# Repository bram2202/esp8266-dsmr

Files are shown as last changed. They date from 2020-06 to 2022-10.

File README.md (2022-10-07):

# PLEASE NOTE, THIS PROJECT IS NO LONGER BEING MAINTAINED
The same functionality can be achieved with [[EspHome]](https://esphome.io/components/sensor/dsmr.html?highlight=dsmr).<br/>
The PCB can be used with the correct [[CONFIG]](https://gist.github.com/bram2202/d75b34a9d672cc8032f55d6f79cfb718)
* * *

# esp8266-dsmr

A ESP8266 based DSMR reader, posting messages onto MQTT.<br/>
Can be powered directly from the meter itself, no external power supply needed*.<br/>
<sup><i>* if enough power can be supplied by the meter.</i></sup>

The code should work on DSRM v2.2 and higher, only tested on V4.2.<br/>
Supports Dutch and Belgian smart meters.<br/>

Can be used with Home Assistant (mqtt auto discover)

## Board in action
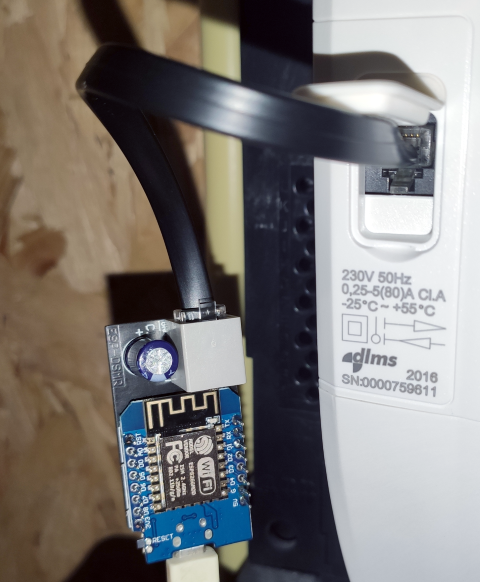
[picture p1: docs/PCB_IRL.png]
esp8266-dsmr


## Requirements 
* Arduino IDE / VS code
* ESP8266 board (Wemos/LOLIN D1 mini/ESP01/NodeMCU)
* Basic soldering and wiring skills
* (For Wemos d1 mini) CH340G driver [[link]](https://wiki.wemos.cc/downloads)
* Prototype board / breadboard / PCB
* RJ11/12/25 cable

## Library dependencies
- [PubSubClient](https://pubsubclient.knolleary.net) - MQTT client
- [Core for ESP8266](https://github.com/esp8266/Arduino) - Arduino core for ESP8266 WiFi chip

## Home Assistant

If MQTT Discovery is enabled in Home Assistant [INFO](https://www.home-assistant.io/docs/mqtt/discovery/), <br/>
the majority of the entities are auto-created and can be found on the integration page.<br/>
Its posible to disale the gas and phase entities in the settings, [See Settings](#Settings).

## Messages

The `MQTT_TOPIC` consists of "ESP_DSMR_" + ESP chip ID.<br/>
For example: `ESP_DSMR_C491F3`

### Info
| Name | unit | DSMR code | MQTT topic |
|:----  |:---|:--- |:---|
| DSMR version | - | 1-3:0.2.8 | <MQTT_TOPIC>/version | 
| Status | online | - | <MQTT_TOPIC>/status | 

### Power
| Name | unit | DSMR code | MQTT topic |
|:----  |:---|:--- |:---|
| current power consumption | kW | 1-0:1.7.0 | <MQTT_TOPIC>/power/consumption | 
| current power production | kW | 1-0:2.7.0 | <MQTT_TOPIC>/power/production | 
| total consumption tariff 1 | kWh | 1-0:1.8.1 | <MQTT_TOPIC>/power/total_consumption_tariff_1 |
| total consumption tariff 2 | kWh | 1-0:1.8.2 | <MQTT_TOPIC>/power/total_consumption_tariff_2 |
| total production tariff 1 | kWh | 1-0:2.8.1 | <MQTT_TOPIC>/power/total_production_tariff_1 |
| total production tariff 2 | kWh | 1-0:2.8.2 | <MQTT_TOPIC>/power/total_production_tariff_2 |
| power tariff | [See tariffs](#tariffs) | 0-0:96.14.0 | <MQTT_TOPIC>/power/power_tariff |
| short power outages | - | 0-0:96.7.21 |<MQTT_TOPIC>/power/short_power_outages |
| long power outages | - | 0-0:96.7.9 |<MQTT_TOPIC>/power/long_power_outages |
| instant current phase 1 | A | 1-0:31.7.0 |<MQTT_TOPIC>/power/phase_1/current |
| instant current phase 2 | A | 1-0:51.7.0 |<MQTT_TOPIC>/power/phase_2/current |
| instant current phase 3 | A | 1-0:71.7.0 |<MQTT_TOPIC>/power/phase_3/current |
| instant consumption phase 1 | kW | 1-0:21.7.0 |<MQTT_TOPIC>/power/phase_1/consumption |
| instant consumption phase 2 | kW | 1-0:41.7.0 |<MQTT_TOPIC>/power/phase_2/consumption |
| instant consumption phase 3 | kW | 1-0:61.7.0 |<MQTT_TOPIC>/power/phase_3/consumption |
| instant production phase 1 | kW | 1-0:22.7.0 |<MQTT_TOPIC>/power/phase_1/production |
| instant production phase 2 | kW | 1-0:42.7.0 |<MQTT_TOPIC>/power/phase_2/production |
| instant production phase 3 | kW | 1-0:62.7.0 |<MQTT_TOPIC>/power/phase_3/production |
| short drops phase 1 | - | 1-0:32.32.0 | <MQTT_TOPIC>/power/phase_1/drops |
| short drops phase 2 | - | 1-0:52.32.0 | <MQTT_TOPIC>/power/phase_2/drops |
| short drops phase 3 | - | 1-0:72.32.0 | <MQTT_TOPIC>/power/phase_3/drops |
| short peaks phase 1 | - | 1-0:32.36.0 | <MQTT_TOPIC>/power/phase_1/peaks |
| short peaks phase 2 | - | 1-0:52.36.0 | <MQTT_TOPIC>/power/phase_2/peaks |
| short peaks phase 3 | - | 1-0:72.36.0 | <MQTT_TOPIC>/power/phase_3/peaks |
| timestamp| - | 0-0:1.0.0 | <MQTT_TOPIC>/power/timestamp |
| device id | - | 0-0:96.1.1 | <MQTT_TOPIC>/power/device |

### Gas
| Name | unit | DSMR code | MQTT topic |
|:----  |:---|:--- |:---|
| total gas | m3 | 0-1:24.2.1 | <MQTT_TOPIC>/gas/total |
| timestamp| - | 0-1:24.2.1| <MQTT_TOPIC>/gas/timestamp |
| device id | - | 0-1:96.1.0 | <MQTT_TOPIC>/gas/device |

## Tariffs
The meter has a power tariff property, and is used for the total consumption/production counters.<br/>
The values for the day and night tariffs are different in the Netherlands compared to Belgium.
| Country | tariff | value |
|:---- |:---- |:---- |
| NL | Night (low) | tariff_1 |
| NL | Day (high) | tariff_2 |
| BE | Night (low) |tariff_2 |
| BE | Day (high)| tariff_1 |

## Settings
Copy `Settings.example.h` to `Settings.h` and fill in the correct data.

| Setting | default | Description|  
|:--- |:----- |:---|
| WIFI_HOSTNAME | ESP-DSMR | device name on network |
| WIFI_SSID | - | Wifi name to connect to |
| WIFI_PASSWORD | - | Wifi password |
| MQTT_BROKER | - | MQTT broker address |
| MQTT_PORT | 1883 | MQTT broker port |
| MQTT_USER_NAME| - | MQTT user name |
| MQTT_PASSWORD | - | MQTT password |
| AUTOCONFIG_GAS | true | Setup gas entity in HA |
| AUTOCONFIG_POWER_EXTENDED | true | Setup all power entities in HA |
| LOG_LEVEL | INFO | ( DEBUG / INFO / WARN ) |

## Circuit
View [scheme (pdf)](https://github.com/bram2202/esp8266-dsmr/blob/master/PCB/schematic.pdf).

Using a level shifter inverter to get the serial output from the meter into the ESP.<br>
The board can be powered directly from the meters power supply <i>(this can vary between models)</i>.

## Custom PCB
Create your own with the [Gerber files (zip)](https://github.com/bram2202/esp8266-dsmr/blob/master/PCB/gerber.zip)

## PCB case
I designed a case to be 3D printed, it fits the board loosely, and is meant to be glued shut

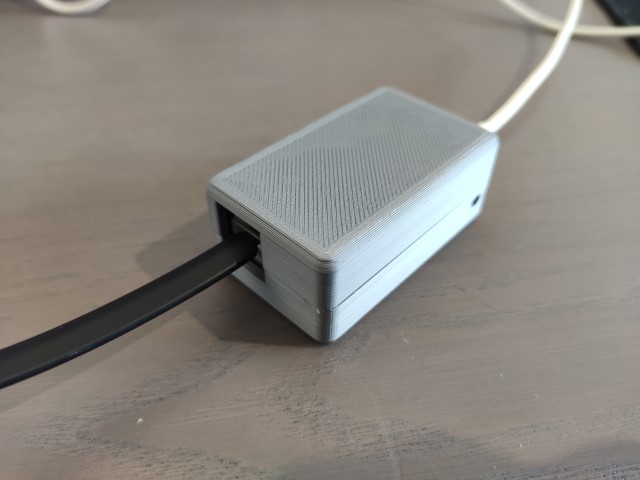
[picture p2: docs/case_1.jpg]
esp8266-dsmr esp8266-dsmr case


STL files are found in the [STL folder](https://github.com/bram2202/esp8266-dsmr/tree/master/STL)

## Parts
| Type | Amount |
|:---|:---|
| ESP8266 board| 1 |
| Prototyping board or PCB | 1 |
| 2.2k resistor (0805) | 2 |
| 1k resistor (0805) | 1 |
| BC547 or BC817 (SOT-23) | 2 | 
| 470uf cap. 8x12mm | 1 | 

## DSMR connection

Connecting to the DSMR with a RJ11/12/25 (6p6c or 6p4c) cable plugged into the Port 1 (P1), found on all supported smart meters.

| DSRM P1 | Description | PCB Pin |
|:---|:---|:---|
| 1* | +5v | 6 (5v) |
| 2 | Request | 5 (5v) |
| 3 | Data GND| 4 (GND) |
| 4 | N.C. | N.C. |
| 5 | Data | 2 (Data)|
| 6* | Power GND | 1 (GND) |

`* 1 and 6 are not needed if powered by USB.`

# Known issues
- Some DSMR cannot deliver enough power to run the Wemos stably.<br> 
Connect a 5V usb supply to fix this.

# Missing properties?
Are you missing a property? don't be afraid to open a [issue](https://github.com/bram2202/esp8266-dsmr/issues), or contribute to this repo yourself!

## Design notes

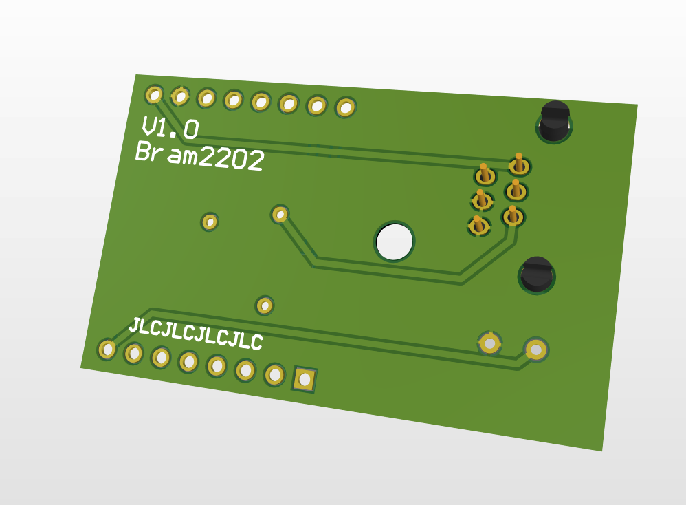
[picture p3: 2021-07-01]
docs/DSMR_bottem.png

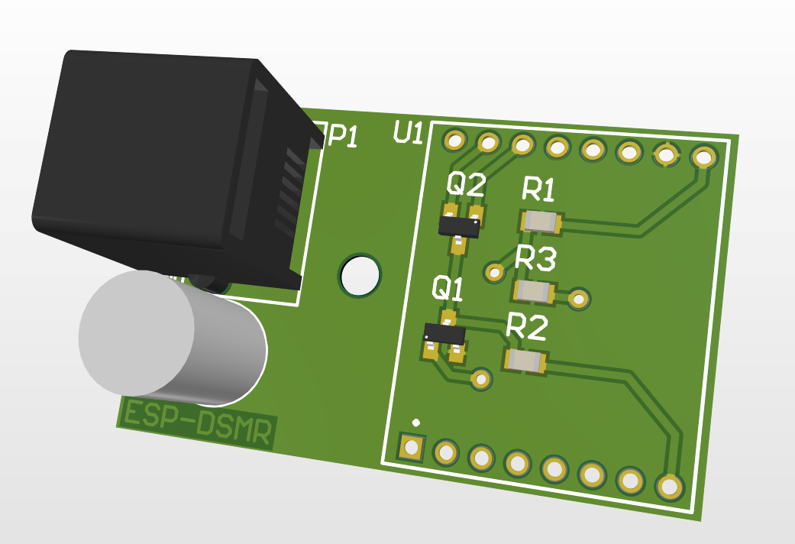
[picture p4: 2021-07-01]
docs/DSMR_top.png

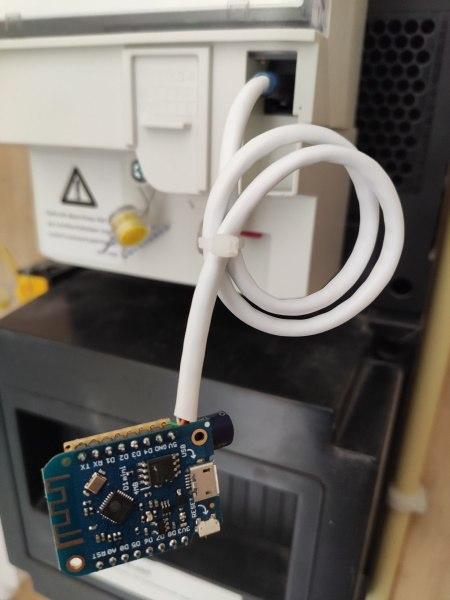
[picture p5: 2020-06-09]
docs/esp8266-dsmr.jpg

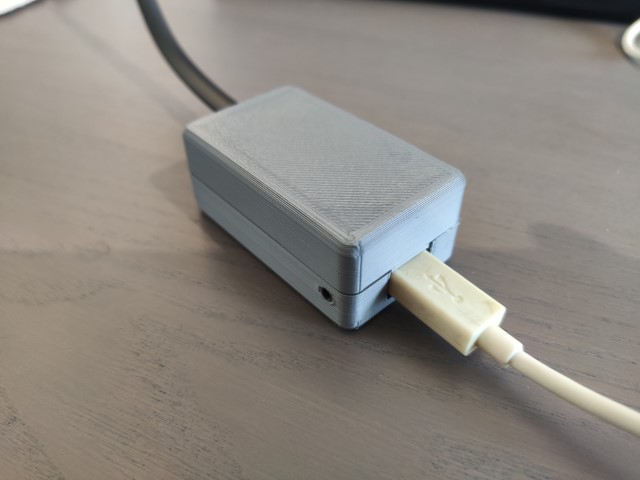
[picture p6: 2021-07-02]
docs/case_2.jpg

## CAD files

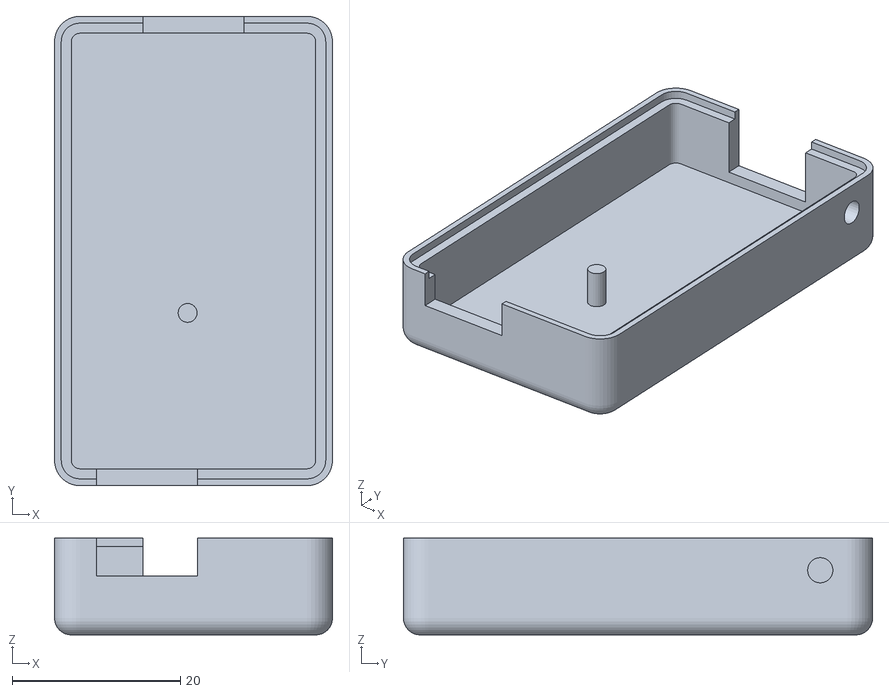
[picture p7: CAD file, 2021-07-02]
STL/case_bottem.stl
33.0 x 55.7 x 11.5

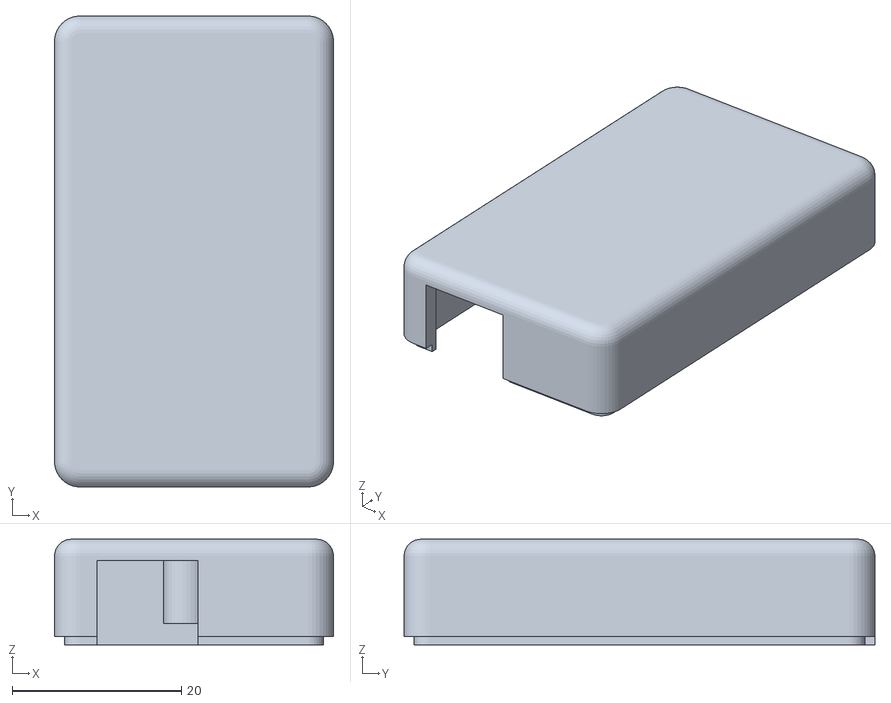
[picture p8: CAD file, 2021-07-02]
STL/case_top.stl
33.0 x 55.7 x 12.5

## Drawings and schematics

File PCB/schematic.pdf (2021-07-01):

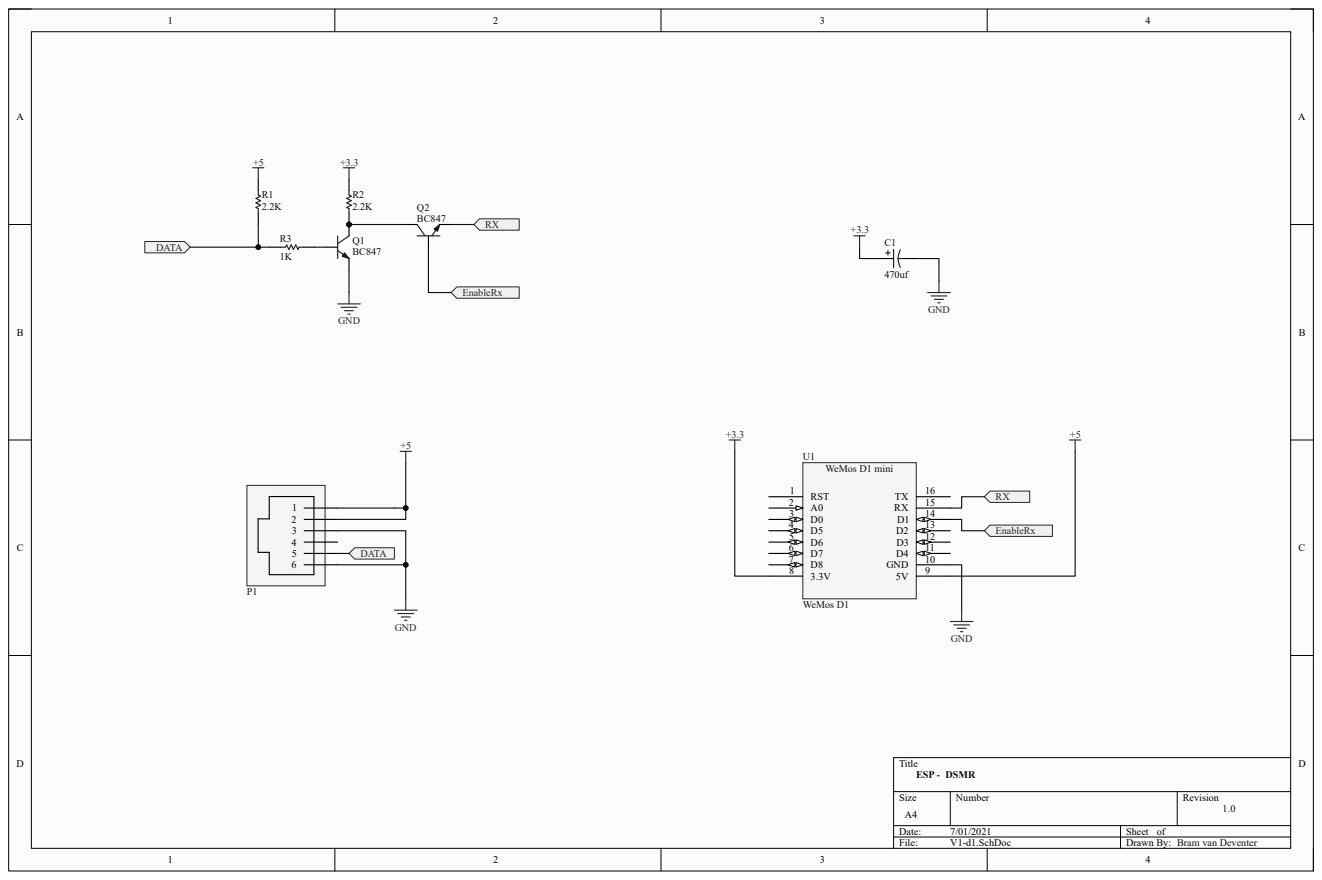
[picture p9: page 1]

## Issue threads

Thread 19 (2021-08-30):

Gasmeter op kanaal 2

peterjohan52, 2021-08-30:
Als de gasmeter op kanaal 2 zit, hoe los je dat op?

0-1:96.1.0()
0-1:24.2.1(700101010000W)(00000000)
0-2:24.1.0(003)
0-2:96.1.0(4730303339303031383433313135303138)
0-2:24.2.1(210830122505S)(01501.449*m3)

bram2202, 2021-08-31:
Je zou de `key` in de `esp8266-dsmr.ino` (regel 60, 61 en 62) kunnen aanpassen om het 2e kanaal te gebruiken.
Lijkt er op dat het eerste kanaal niet gebruikt wordt, dus zou geen probleem moeten zijn.

peterjohan52, 2021-08-31:
Prima, Marcel gebruikt via “ota” een .bin file. Ik weet niet welke bestanden er in zitten en hoe ik die maak. Is er ergens een handleiding? Gaat de gasmeter op kanaal 2 in de toekomst ook in het bestand komen?

bram2202, 2021-08-31:
Ik weet niet hoe dat project er uit ziet/werkt.
op dit moment zit er nog een bug in OTA.
Als je het project lokaal uit checked kan je hem met VsCode of de Arduinio IDE aanpassen, builden en flashen.

Ik zie in de [documentatie ](http://domoticx.com/p1-poort-slimme-meter-hardware/) dat de kanalen kunnen worden gebruikt voor zowel `gas`, `water` en `thermal: Heat or Cold`.
Hij is nu hardcoded voor kanaal 1 gas, maar als er meer gebruikers zijn met ander configs is het misschien wel de moeiten om dat configurable te maken. maar voorlopig zat dat nog niet in de planning.

peterjohan52, 2021-08-31:
Klopt precies, in P1 monitor, zit er nu een switch om het gaskanaal te kiezen. DSMR reader heeft het zo geschreven, dat het automatisch gaat. Net als Homewizzard. Liander wilde mijn gasmeter niet terug zetten op 1, Het werkt en ze zien er geen probleem in. In de toekomst zal het wel vaker gebeuren, zij het sporadisch, dat er een gasmeter wordt vervangen.

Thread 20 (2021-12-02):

Software Arduino

QFaas, 2021-12-02:
Hoi Bram,
Ik heb eens een vraagje, ik heb proberen je Github over ESP8266-dsmr proberen namaken, het is mij tot in alle hardware gelukt dit 1 op 1 te kopieren en volgens het schema te zetten. Alleen nu loop ik zelf klein beetje stuk op het gedeelte van Arduino, ik heb alle bestanden gekopieerd van deze Github maar ik zat eens te kijken in het hoofd Arduino bestand (esp8266-dsmr.ino) daarin staan nog enkele bestanden maar die niet te vinden zijn in jou Github over ESP8266-dsmr. Nu hebben wij eens gezocht op internet die bestanden zijn inderdaad ergens te vinden maar al die andere bestanden bevatten ook nog een andere 'include' maar wij weten totaal niet of deze bestanden er allemaal in horen. Zou je eens contact met mij willen opnemen om mij verder wegwijs te helpen.
Ik hoop voldoende info te hebben gegeven en mij hierbij verder wil helpen ;).
Gr,

Quinten

QFaas, 2021-12-02:
Ik hoop dat je mij hiermee zo snel mogelijk kan helpen omdat het een relatieve korte deadline heeft :()

bram2202, 2021-12-02:
Hey.

Ik ga er van uit dat je de includes bedoeld zoals `ESP8266WiFi.h`?

Onder het kopje [library-dependencies](https://github.com/bram2202/esp8266-dsmr#library-dependencies) zie je welke libraries er gebruikt zijn,
deze zijn de installeren in de Arduino tool -> `Tools` -> `Library Manager`.

QFaas, 2021-12-02:
Ja dat bedoel ik inderdaad,
Maar die library dependescies moet je daar alle bestanden van kopiëren of
wat is de bedoeling?

Op do 2 dec. 2021 13:45 schreef Bram van Deventer ***@***.***
>:

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

bram2202, 2021-12-02:
Nee, via de `Library Manager` download je ze in een folder van de Arduino IDE zelf, bij het bouwen haalt hij ze daar uit.
Je kan zelf de folder aanmaken en files kopiëren, maar via de manager is makkelijker.

bram2202, 2021-12-02:
https://www.arduino.cc/en/Guide/Libraries

QFaas, 2021-12-02:
Deze site moet ik alle libraries halen want ik keek in esp8266wifi.h maar in dat bestand staan nog bestanden met include in?Verzonden vanaf mijn Galaxy
-------- Oorspronkelijk bericht --------Van: Bram van Deventer ***@***.***> Datum: 02-12-2021  14:47  (GMT+01:00) Aan: bram2202/esp8266-dsmr ***@***.***> Cc: QFaas ***@***.***>, Author ***@***.***> Onderwerp: Re: [bram2202/esp8266-dsmr] Software Arduino (Issue #20)
https://www.arduino.cc/en/Guide/Libraries

—You are receiving this because you authored the thread.Reply to this email directly, view it on GitHub, or unsubscribe.Triage notifications on the go with GitHub Mobile for iOS or Android.

QFaas, 2021-12-02:
Hoi bram, zou je misschien contact met mij kunnen opnemen om misschien het een klein beetje te verduidelijken?Verzonden vanaf mijn Galaxy
-------- Oorspronkelijk bericht --------Van: Bram van Deventer ***@***.***> Datum: 02-12-2021  14:47  (GMT+01:00) Aan: bram2202/esp8266-dsmr ***@***.***> Cc: QFaas ***@***.***>, Author ***@***.***> Onderwerp: Re: [bram2202/esp8266-dsmr] Software Arduino (Issue #20)
https://www.arduino.cc/en/Guide/Libraries

—You are receiving this because you authored the thread.Reply to this email directly, view it on GitHub, or unsubscribe.Triage notifications on the go with GitHub Mobile for iOS or Android.

QFaas, 2021-12-03:
Hallo Bram,
Wij hebben inderdaad de library kunnen toevoegen over de PubSubClient die heeft ie gevonden maar de library over Core For ESP8266 kunnen wij niet vinden hoe jij hebt beschreven in Arduino, enig idee?
Gr Quinten

bram2202, 2021-12-03:
Als kijkt op de pagina van de Core lib: https://github.com/esp8266/Arduino
Staat er boven aan `Installing with Boards Manager`, die stappen moet je volgen.

QFaas, 2021-12-03:
Als wij op Verifieren klikken krijgen wij de melding dat het bestand ESP8266Wifi.h: no Such file in directory

QFaas, 2021-12-03:
Hoe krijgen wij dit voor elkaar wanneer arduino dit bestand wel pakt?

bram2202, 2021-12-03:
Reboot?

QFaas, 2021-12-03:
Dit werkt helaas niet, we krijgen wel dezelfde melding maar dan met ArduinoJSON.h: no Such file in directory
Moeten wij hier nog iets specifieks voor doen?
Ps, sorry voor alle vragen :P

QFaas, 2021-12-03:
Wij willen gewoon graag dat het werkt vandaar

bram2202, 2021-12-03:
Ik zie dat er nog een lib mist in mijn readme.
Maar als je je foutmelding in  [google gooit](https://letmegooglethat.com/?q=+ArduinoJSON.h%3A+no+Such+file+in+directory)
Dan zie je dat je die ook moet toevoegen in de `Library Manager`

QFaas, 2021-12-03:
Dit hebben wij nu gedaan, maar nu worden er fouten aangegeven die in de ArduinoJson code zitten? kan dit misschien zijn voor een verkeerde library of niet?

QFaas, 2021-12-03:
wij hebben nameljik de 6.18.5 library gedownload van ArduinoJSON

bram2202, 2021-12-03:
Ik heb hier ook de 6.18.5 versie geprobeerd, en ik kan gewoon builden.
Welke foutmeldingen krijg je?

QFaas, 2021-12-03:
Dag bram, het is gelukt de codering kwamen geen foutmeldingen meer maar in het ino bestand staat er 2 verschillende pinnen zoals lvlpin en en rx pin, wat houd die lvl pin in? De aansluitingen met de jumpwires hebben wij gezet op d1(dezelfde pin als op wemos), RX, d7, 3.3v of 5v(vin) en gndVerzonden vanaf mijn Galaxy
-------- Oorspronkelijk bericht --------Van: Bram van Deventer ***@***.***> Datum: 03-12-2021  15:04  (GMT+01:00) Aan: bram2202/esp8266-dsmr ***@***.***> Cc: QFaas ***@***.***>, Author ***@***.***> Onderwerp: Re: [bram2202/esp8266-dsmr] Software Arduino (Issue #20)
Ik heb hier ook de 6.18.5 versie geprobeerd, en ik kan gewoon builden.
Welke foutmeldingen krijg je?

—You are receiving this because you authored the thread.Reply to this email directly, view it on GitHub, or unsubscribe.Triage notifications on the go with GitHub Mobile for iOS or Android.

QFaas, 2021-12-04:
Hoi Bram, ik heb de code nu werkend, maar ik heb 1 ander klein probleempje, en dat is dat ik de esp8266 niet kan vinden op het netwerk dus zo ook niet aan mijn Home Assistant kan toevoegen heb je enig idee?

QFaas, 2021-12-04:
de code is trouwens geupload naar de esp met de Settings.h ingevuld

QFaas, 2021-12-04:
Dag Bram, ik kreeg hem inderdaad op het netwerk (voor heel even), toen heb ik hem eruit gedaan omdat ik naar de P1 poort moest gaan, maar daarna is hij niet meer op het netwerk gekomen, enig idee? want hij komt nu ook niet meer op de router als een wireless client etc... Hoe kan ik dit oplossen dat hij altijd op het netwerk blijft?

QFaas, 2021-12-04:
Bram ik heb nu alles werkend, code, dat hij op het netwerk gevonden wordt, alleen hoe kan je hem nu toevoegen in je Home Assistant, ik heb geprobeerd via MQTT broker in home assistant integratie, dit zonder resultaat, ik heb ook geprobeerd om via de integratie om via de DSMR Slimme Meter integratie te proberen dit ook zonder resultaat, enig idee?

bram2202, 2021-12-05:
Goed om te horen dat je het toch werkend hebt gekregen.
Je hebt inderdaad een losse MQTT broker nodig, de gegevens daarvan (ip/poort/user/password) moet je dan instellen in de config file.
Je kan met een programma zoals [MQTT-Explorer](https://github.com/thomasnordquist/MQTT-Explorer) kijken of er überhaupt wel een bericht op het topic wordt gezet.
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
QFaas, 2021-12-09:
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

QFaas, 2021-12-09:
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

QFaas, 2021-12-09:
Hebben jullie hier meer aan?

QFaas, 2021-12-09:
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

Dit is als ik al deze stappen heb gedaan

QFaas, 2021-12-09:
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

Dit heb ik als logboek met mqtt

QFaas, 2021-12-09:
dat is inderdaad het ip van de esp wat hij aangeeft die 107 dat zie ik in mijn netwerk

bram2202, 2021-12-09:
Welke waardes zitten in "power_consumption"?
lijkt er op dat hij alleen online door geeft, en geen values

QFaas, 2021-12-09:
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

dit geeft hij aan als ik erop klik

bram2202, 2021-12-09:
ja, de ESP heeft geen waardes ontvangen.

Waar heb je hem ingeprikt, ondersteund deze DSMR?
En hoe ziet je circuit er uit?

QFaas, 2021-12-09:
het is dsmr 4
het circuit ziet eruit als diegene die in het schema van jou staat

bram2202, 2021-12-09:
Zou je daar een foto van kunnen maken?

QFaas, 2021-12-09:
alleen 1 klein dingetje dat zit op een breadboard, dus weet niet of het zo makkelijk te zien is op foto :(

QFaas, 2021-12-09:
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

dit is het aansluitschema in schets, ik zal zo nog een foto maken

QFaas, 2021-12-09:
Verzonden vanaf mijn Galaxy

QFaas, 2021-12-09:
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

QFaas, 2021-12-09:
sorry maar het is vrij lastig om een foto te maken van zoveel kabels door elkaar

QFaas, 2021-12-09:
maar dat plaatje met dat breadboard erop met RX etc is hoe wij het hebben nagemaakt maar dan met natuurlijk niet van die hele lange ijzeren dingen natuurlijk :P

bram2202, 2021-12-09:
Dat is inderdaad lastig te zien zo.
Kan je van je verbinding met de DSMR meten tussen pin1 en pin6 of dit `+5v` of `-5v` is?

QFaas, 2021-12-09:
wacht
pin 1 en pin 6 is?

QFaas, 2021-12-09:
lijkt mij VIN POORT en GND, klopt dit?

bram2202, 2021-12-09:
Klopt, maar dit moet je dan even meten zonder dat de rest van het circuit er aan hangt, echt alleen de DSMR zelf.
Dit om er zeker van te zijn dat het geheel niet omgedraaid zit.

QFaas, 2021-12-09:
is goed ik ga even meten ik laat het zo weten

QFaas, 2021-12-09:
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

Ik heb net proberen meten maar ik krijg geen 5v terug op het scherm hoor misschien dat ik het verkeerd heb aangesloten?

QFaas, 2021-12-09:
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

het Zou deze moeten zijn kweet niet of je hier wat aan hebt

QFaas, 2021-12-09:
ik heb het probleem gevonden denk ik bram, op mijn esp meet de VIN poort maar 0.18 max dus ik denk dat die poort gewoon kapot is, en omdat ik een dsmr 4.0 heb kan die niet zelf voeden en moet er een 5v aan maar omdat hij het niet doet kan hij inderdaad alleen aan maar geen data etc ontvangen

QFaas, 2021-12-09:
en die werkt niet, dus ik ga kijken of ik een nieuwe esp8266 chip mee kan krijgen zodat ik het kan zien dat de 5v werkt

QFaas, 2021-12-09:
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

bram2202, 2021-12-10:
> ik heb het probleem gevonden denk ik bram, op mijn esp meet de VIN poort maar 0.18 max dus ik denk dat die poort gewoon kapot is, en omdat ik een dsmr 4.0 heb kan die niet zelf voeden en moet er een 5v aan maar omdat hij het niet doet kan hij inderdaad alleen aan maar geen data etc ontvangen

Ik bedoelde pin 1 en 6 van je DSMR aansluiting niet van je ESP.
Het zou misschien kunnen dat je deze aansluiting andersom hebt gemaakt, dus pin 1 == 6, 2 == 5 etc..

Als je een USB kabel aan je ESP hebt hangen zou dit voldoende moeten zijn.

QFaas, 2021-12-10:
sorry maar had je vraag verkeerd begrepen ik zal vandaag eens kijken

QFaas, 2021-12-10:
Alleen een ander vraagje Bram, in jou schema staat ook Enable RX, en RX,  die Enable RX waarvoor staat die, ik heb hem namelijk op D7 staan (dat is en andere RX) maar wat is dat bij jou

QFaas, 2021-12-10:
Bram ik heb net gemeten er komt 5v door pin 1 en 6 zo te zien in mijn dsmr

QFaas, 2021-12-10:
En nog een ander dingetje, ik heb nu die nieuwe esp, alleen die komt weer totaal niet snel in de mqtt hoe kan ik dit probleem oplossen?

bram2202, 2021-12-10:
`Enable RX` zorgt er voor dat de levelshifter gaat werken (het 5v signaal omzetten naar 3.3v), zo wordt de ESP niet opgeblazen.
Officieel zou die alleen 3.3v input kunnen hebben.

Die pin waar `Enable RX` op zit moet dus wel HOOG zijn, anders komt de data niet door.
Ik weet niet of de pin nummer tussen een ESP8266 en ESP32 overeen komen.

QFaas, 2021-12-10:
je hebt zelf de wemos gepakt dit is op basis van 8266?

QFaas, 2021-12-10:
Niet?

QFaas, 2021-12-10:
De chip zelf al is geflashed, dus daaraan kan het niet liggen, maar het rare is ook dat ik probeer de code via poort 1 maar die pakt die niet, dus hhij ziet het niet als poort, terwijl die andere esp (die 5v kapot is) die pakt die wel

QFaas, 2021-12-10:
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

bram2202, 2021-12-13:
Hallo Quinten,

De laatste genoemde problemen lijkt om een drive issue.
De code zoals hij nu op Git staat werkt (geverifieerd) als er geen data binnen komt op de ESP tijdens debuggen moet je toch nog maar eens goed kijken naar de gebruikte pinnen in de code en die op je ESP.

success.

Closed 2021-12-13.

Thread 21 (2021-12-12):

Gas not working and has the wrong label

Dutchone, 2021-12-12:
Hi,

I build the pcb as noted in the files,

But i cant get the gas to read, it makes the sensor but no data is presented, i tested it with my old p1 monitor, and that works with the same key adress.

Any idea what is going wrong?

Also gas is noted as kWh but has to be M³.

Nick

bram2202, 2021-12-12:
Hey Nick,

Are any of the other P1 values (power) being send ?
The unit is indeed wrong.

Dutchone, 2021-12-12:
Hey Bram,

Yes everything for a L1 meter is coming through, so i suspect its a telegram error somewhere.

I suspect the unique name is gas/total. The name is total_gas.

But for other messages the unique name is phase_3_peak, and not phase/3/peak

Dutchone, 2021-12-13:
Hi Bram,

Dit a bit more of a deep dive with mqtt explorer, Gas telegrams are being send only in HA they are not reading.

Just to keep you updated.

Dutchone, 2021-12-13:
Well After a quick update if found the problem,

There is a Slash missing.

What is in the github:
 autoconfPayload["availability_topic"] = _identifier + "gas/total/status";

What is should be:
 autoconfPayload["availability_topic"] = _identifier + "/gas/total/status";

Thats why HA is looking in the wrong topic
ESP_DSMR_1994BDgas/total/status

And not in "ESP_DSMR_1994BD/gas/total/status" as is should be

    if (AUTOCONFIG_GAS)
    {
        // Gas
        autoconfPayload["device"] = device.as<JsonObject>();
        autoconfPayload["availability_topic"] = _identifier + "/gas/total/status";
        autoconfPayload["state_topic"] = _identifier + "/gas/total";
        autoconfPayload["last_reset_topic"] = _identifier + "/gas/total/reset";
        autoconfPayload["name"] = _identifier + "_total_gas";
        autoconfPayload["unit_of_measurement"] = "m³";
        autoconfPayload["unique_id"] = "gas_total";
        autoconfPayload["icon"] = "mdi:counter";
        autoconfPayload["last_reset_value_template"] = "1970-01-01T00:00:00+00:00";
        serializeJson(autoconfPayload, mqttPayload);
        _mqttPublisher.publish("homeassistant/sensor/" + _identifier + "/total_gas/config", &mqttPayload[0], false);
        autoconfPayload.clear();
    }
}

bram2202, 2021-12-13:
Ah my bad, can you commit your code and create Pull Request for this?

Dutchone, 2021-12-13:
Nah I'm already thankfull you made this,

When I have time I will try, since I never made a pull before.

Closed 2021-12-13.

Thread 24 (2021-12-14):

MQTT komt niet in beeld

QFaas, 2021-12-14:
Hoi Bram, ik heb de chip weer aan de praat gekregen met de juiste mqtt gegevens erop, maar hij komt wederom niet in home Assistant, en ook niet in de mqtt explorer?

QFaas, 2021-12-14:
kan dit misschien komen omdat ik een virtuele machine gebruik voor mijn home assistant?

bram2202, 2021-12-15:
Hallo Quinten,

Deze vragen hebben niets meer te maken het dit Github project zelf.

Ik wil je best helpen maar een issue aanmaken is hiervoor niet de juiste manier,
daarvoor zijn bijvoorbeeld [Stackoverflow](https://stackoverflow.com/) of nog beter de [HA community](https://community.home-assistant.io/).
Als je hier je vragen op post kan iedereen die wil er op reageren, en ben je niet afhankelijk van 1 persoon.

Maar misschien is het verstandig om eerst even zelf onderzoek te doen naar hoe MQTT werkt en wat de beperkingen zijn i.p.v. elke vraag zo maar de posten als een issue, en een kant en klaar antwoord te verwachten.
Veel van je vragen zijn al eens door iemand gesteld en zijn te vinden als je Google gebruikt, Stackoverflow is hierin een handige en betrouwbare bron.

Succes

QFaas, 2021-12-15:
Bram, ik snap dat ik niet alles moet vragen maar dit gaat wel over het GitHub project want als ik alles 1 op 1 hetzelfde gedaan heb als in jou GitHub is dit toch raar dat dit bij mij niet werkt en bij jou wel? Daarover gaan deze vragen... want de MQTT staat immers wel in jou GitHub, dus vandaar dat ik daar vragen over aan het stellen ben..

QFaas, 2021-12-15:
Dus de vraag die nu dan bovenop komt, welke libraries heb je precies allemaal gedownload voor dit Project in Arduino, want ik krijg het idee dat wij misschien verkeerde libraries hebben gedownload en dat het daar misschien aan licht.

QFaas, 2021-12-15:
En het klopt sommige dingen gaat niet over het GitHub project maar ik dacht jij bent hier ook in aanraking mee gekomen dus misschien weet je dat wel

Closed 2021-12-15.

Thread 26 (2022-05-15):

ESP01 question

hsy400, 2022-05-15:
On ESP01 board which are the corresponding pins that marked on the schematic "RX" and "EnableRx" ?

bram2202, 2022-05-15:
The schematic and code are not designed with a ESP01 in mind, only the ESP8266.
I don't know if its possible to adapt this.

LaySoft, 2022-05-15:
The Readme in the requirements section writes this:
"ESP8266 board (Wemos/LOLIN D1 mini/**ESP01**/NodeMCU)"

bram2202, 2022-05-15:
Ah yes, my bad.
I did not test/add this myself, maybe @diversit can give more info about the pins?

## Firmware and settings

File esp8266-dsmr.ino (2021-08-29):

#include <ESP8266WiFi.h>
#include <ESP8266mDNS.h>
#include <ESP8266HTTPClient.h>
#include <WiFiUdp.h>
#include <ArduinoOTA.h>
#include <ArduinoJson.h>
#include "ESP8266mDNS.h"

#include "MQTTPublisher.h"
#include "WifiConnector.h"
#include "Settings.h"
#include "Logger.h"
#include "AutoConfig.h"

typedef struct
{
  String name;
  String key; // OBIS property key
  int start;  // start of value in string
  int end;    // end  of value in string
  bool online;

  enum
  {
    STRING,
    FLOAT,
    INT
  } valueType;

} Measurement;

const Measurement measurements[] = {
    {"version", "1-3:0.2.8", 10, 12, false, Measurement::STRING},
    {"power/timestamp", "0-0:1.0.0", 10, 23, false, Measurement::STRING},
    {"power/device_id", "0-0:96.1.1", 11, 45, false, Measurement::STRING},
    {"power/consumption", "1-0:1.7.0", 10, 16, false, Measurement::FLOAT},
    {"power/production", "1-0:2.7.0", 10, 16, false, Measurement::FLOAT},
    {"power/total_consumption_tariff_1", "1-0:1.8.1", 10, 20, false, Measurement::FLOAT},
    {"power/total_consumption_tariff_2", "1-0:1.8.2", 10, 20, false, Measurement::FLOAT},
    {"power/total_production_tariff_1", "1-0:2.8.1", 10, 20, false, Measurement::FLOAT},
    {"power/total_production_tariff_2", "1-0:2.8.2", 10, 20, false, Measurement::FLOAT},
    {"power/power_tariff", "0-0:96.14.0", 12, 16, false, Measurement::INT},
    {"power/short_power_outages", "0-0:96.7.21", 12, 17, false, Measurement::INT},
    {"power/long_power_outages", "0-0:96.7.9", 11, 16, false, Measurement::INT},
    {"power/phase_1/short_power_drops", "1-0:32.32.0", 12, 17, false, Measurement::INT},
    {"power/phase_2/short_power_drops", "1-0:52.32.0", 12, 17, false, Measurement::INT},
    {"power/phase_3/short_power_drops", "1-0:72.32.0", 12, 17, false, Measurement::INT},
    {"power/phase_1/short_power_peaks", "1-0:32.36.0", 12, 17, false, Measurement::INT},
    {"power/phase_2/short_power_peaks", "1-0:52.36.0", 12, 17, false, Measurement::INT},
    {"power/phase_3/short_power_peaks", "1-0:72.36.0", 12, 17, false, Measurement::INT},
    {"power/phase_1/current", "1-0:31.7.0", 11, 14, false, Measurement::INT},
    {"power/phase_2/current", "1-0:51.7.0", 11, 14, false, Measurement::INT},
    {"power/phase_3/current", "1-0:71.7.0", 11, 14, false, Measurement::INT},
    {"power/phase_1/consumption", "1-0:21.7.0", 11, 17, false, Measurement::FLOAT},
    {"power/phase_2/consumption", "1-0:41.7.0", 11, 17, false, Measurement::FLOAT},
    {"power/phase_3/consumption", "1-0:61.7.0", 11, 17, false, Measurement::FLOAT},
    {"power/phase_1/production", "1-0:22.7.0", 11, 17, false, Measurement::FLOAT},
    {"power/phase_2/production", "1-0:42.7.0", 11, 17, false, Measurement::FLOAT},
    {"power/phase_3/production", "1-0:62.7.0", 11, 17, false, Measurement::FLOAT},
    {"gas/total", "0-1:24.2.1", 26, 35, false, Measurement::FLOAT},
    {"gas/device_id", "0-1:96.1.0", 11, 45, false, Measurement::STRING},
    {"gas/timestamp", "0-1:24.2.1", 11, 24, false, Measurement::STRING}};

MQTTPublisher mqttPublisher;
WifiConnector wifiConnector;
AutoConfig autoConfig;
WiFiUDP ntpUDP;
String incomingString = "";
bool hasMQTT = false;
bool hasWIFI = false;
Logger logger = Logger("App");
char identifier[24];
int valueState[29];

int rxPin = 3;
int lvlPin = 5;

void setup()
{
  // Start serial ESP8266 RX port (pin 3)
  Serial.begin(115200);
  pinMode(rxPin, FUNCTION_0); // RX

  logger.info("Start setup");

  // Set pin modes
  pinMode(lvlPin, OUTPUT);    // D1
  digitalWrite(lvlPin, HIGH); // Turn on RX Trans

  snprintf(identifier, sizeof(identifier), "ESP_DSMR_%X", ESP.getChipId());

  // Setup Wifi
  wifiConnector = WifiConnector();
  wifiConnector.start();

  // Setup MQTT
  mqttPublisher = MQTTPublisher(identifier);
  mqttPublisher.start();

  // Setup OTA
  ArduinoOTA.setHostname(WIFI_HOSTNAME);
  ArduinoOTA.begin();

  // Sent HA config
  autoConfig = AutoConfig(mqttPublisher, identifier);
  autoConfig.SendConfig();

  logger.info("Setup complete");
}

void loop()
{

  wifiConnector.handle();
  yield();
  ArduinoOTA.handle();
  yield();
  mqttPublisher.handle();
  yield();

  // If serial received, read until newline
  if (Serial.available() > 0)
  {
    incomingString = Serial.readStringUntil('\n');
    handleString(incomingString);
  }
}

// Regex are not supported, so use indexOf and substring
void handleString(String incomingString)
{

  int i;
  int arraySize = sizeof(measurements) / sizeof(measurements[0]);

  for (i = 0; i < arraySize; i++)
  {
    Measurement measurement = measurements[i];
    String obisKey = measurement.key;

    if (incomingString.indexOf(obisKey) > -1)
    {
      // found
      String value = incomingString.substring(measurement.start, measurement.end);
      logger.debug("DEBUG_1 " + obisKey + "=" + value);

      switch (measurement.valueType)
      {
      case Measurement::FLOAT:
        value = String(value.toFloat(), 3);
        break;
      case Measurement::INT:
        value = String(value.toInt());
        break;
      default:
        break;
      }

      // Check if measurement state is offline, if so publish online state and last reset
      if (!measurement.online)
      {
        measurement.online = true;
        mqttPublisher.publish(measurement.name + "/status", "online", true);
        mqttPublisher.publish(measurement.name + "/reset", "1970-01-01T00:00:00+00:00", true);
      }

      // Publish measurement
      mqttPublisher.publish(measurement.name, value, true);
    }
  }
}

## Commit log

2020-08-23 Update Readme
    - Fix debug print
    - Add Know issues
2021-04-15 Reworking parsing of OBIS properties by using a array of measurement structs containing a name (used for topic), OBIS keys, etc. Adding additional properties for Kaifa 304 meter. Added a Logger compo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
    [esp8266-dsmr.ino]
2021-04-26 Fix Readme (WIP)
    - Remove text
    - add back msg table
    - fix code styling
    [esp8266-dsmr.ino]
2021-04-28 Add Arduino core dep.
    Adding Arduino core dependency
2021-06-14 Adding pins
    - Led pint for displaying activity
    - level shifter pin to power level shifter
2021-06-15 Remove led pin
2021-06-16 Adding custom PCB
    - Add Gerber zip
    - Add new schematic
    - Update README
2021-07-01 Update PCB
2021-07-01 Adding PCB img to readme
2021-07-02 Add STL files
    - Update Readme
    - Add STL files
    - Add pictures of case
    - resize main picture
    [case_bottem.stl, case_top.stl]
2021-07-15 Remove high / low tariffs
    - Use tariff 1 and 2 instead of high / low
    - Update README about NL and BE tariff differences.
    - Fix typo's
    [esp8266-dsmr.ino]
2021-08-07 fixed typo in consumption
    [esp8266-dsmr.ino]
2021-08-25 Fix last_reset_topic prop
    - Change last reset topic to +/reset
    - Remove unused config
    - Update config name
    - Update settings example file
    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
2021-08-29 Sending reset DT if online
    - Sends epoch
    [esp8266-dsmr.ino]
